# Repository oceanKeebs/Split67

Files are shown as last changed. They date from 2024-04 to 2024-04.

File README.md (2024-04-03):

# Split67

Split67 is a splitted common 67% ISO DE keyboard layout with processor daughterboards extended by a side case housing a TPS43 touch pad and a 64x128 Oled display. Left and right keyboard Pcb is connected with TRRS using serial communication, right keyboard part and sidecase are connected with TRRS using i2c communication. To support a close contact of the parts, magnets are used.

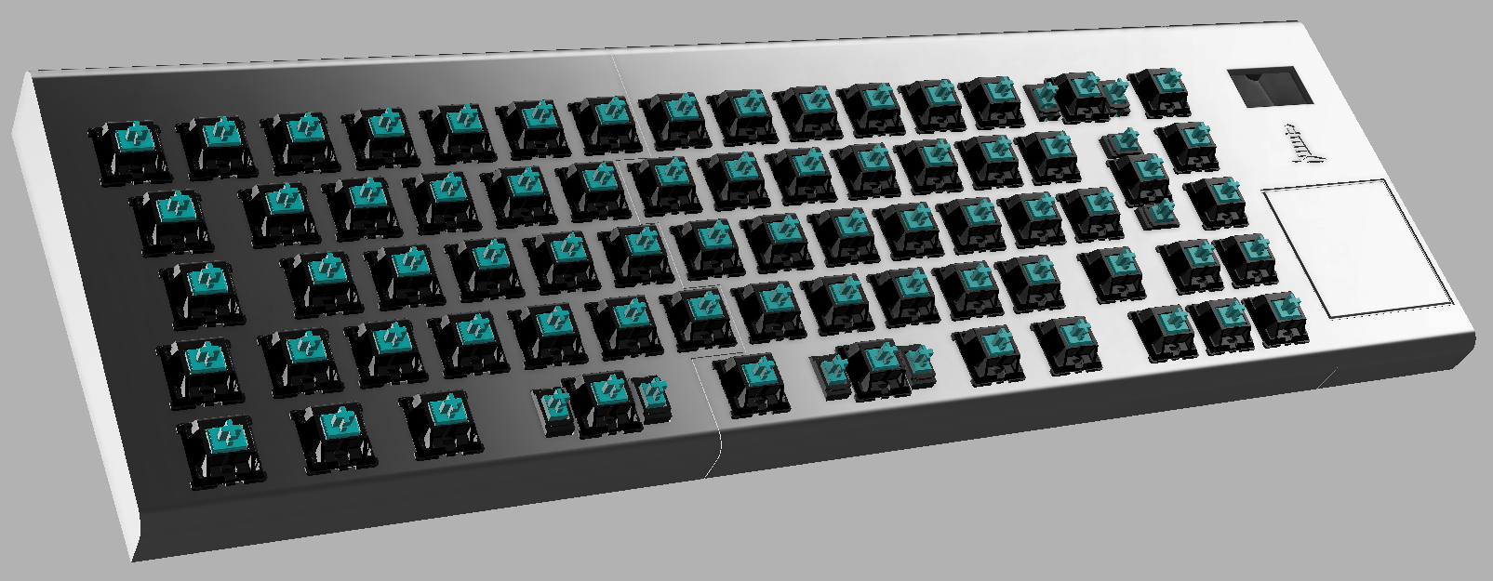
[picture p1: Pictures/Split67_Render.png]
Split67_Render


## QMK Firmware source files

<https://github.com/oceanKeebs/qmk_firmware/tree/master/keyboards/oceankeebs/split67>

## QMK Firmware hex files

**without via support:**
[Split67_defaultHex](HexFiles/oceankeebs_split67_default.hex)

**with via support:**
[Split67_viaHex](HexFiles/oceankeebs_split67_via.hex)

## PCBs

### Processor Board

The processor board includes the ProMicro and connectors for i2c, serial communication and keyboard Pcb control.

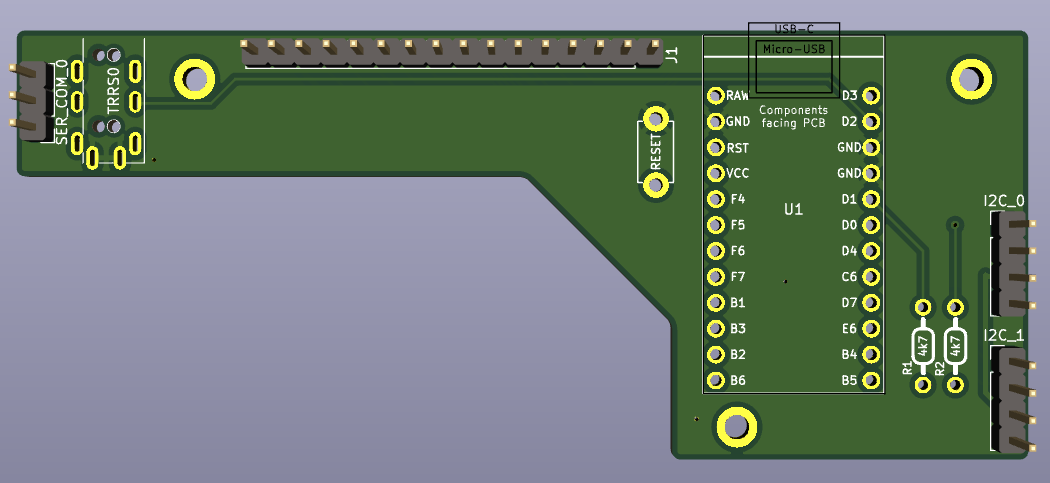
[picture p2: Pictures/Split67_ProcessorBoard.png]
Split67_ProcessorBoard


### Left Pcb

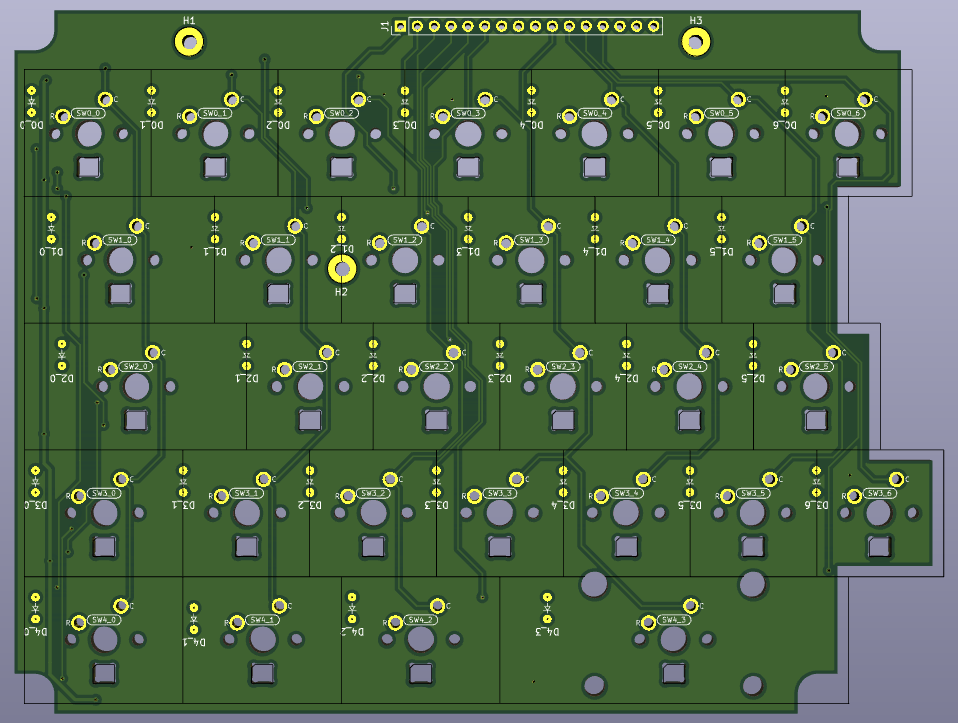
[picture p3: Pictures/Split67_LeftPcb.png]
Split67_LeftPcb


### Right Pcb

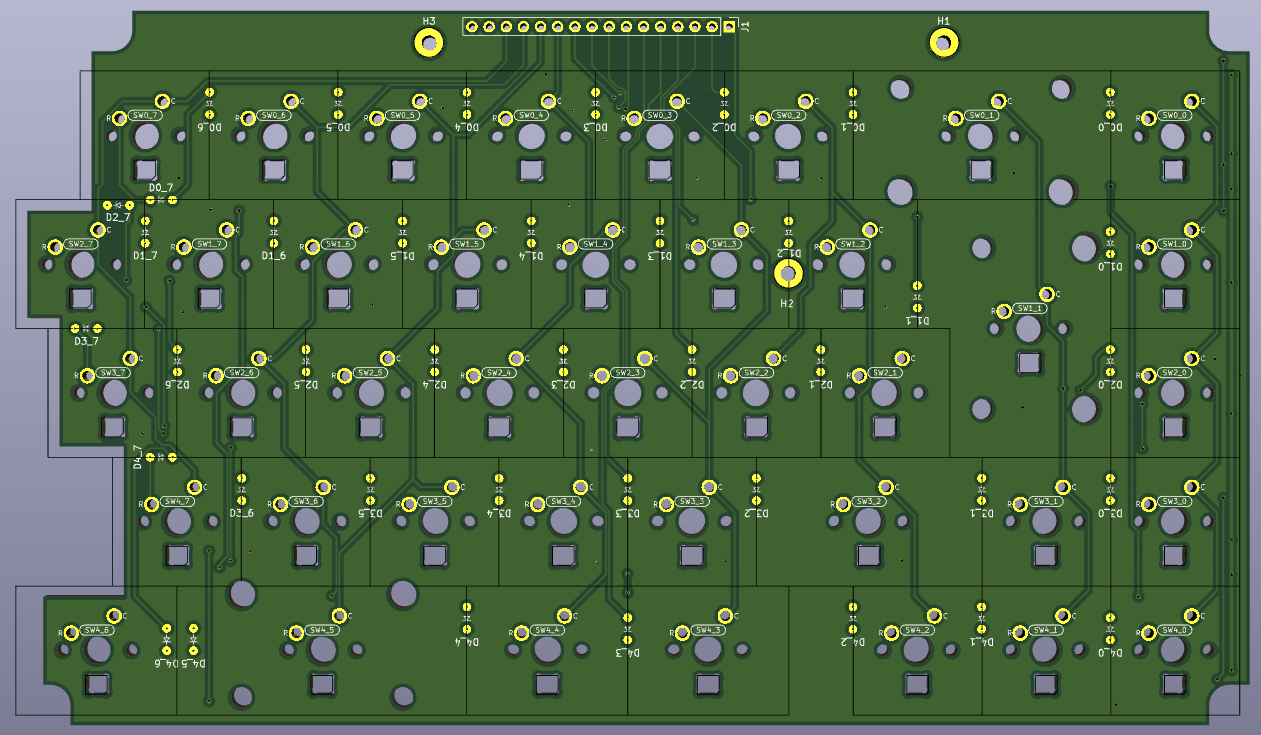
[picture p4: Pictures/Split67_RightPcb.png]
Split67_RightPcb


## Case

### Left keyboard part

[LeftCaseTop_stl](StlFiles/Case_L_B.stl)

[LeftCaseBottom_stl](StlFiles/Bottom_L.stl)

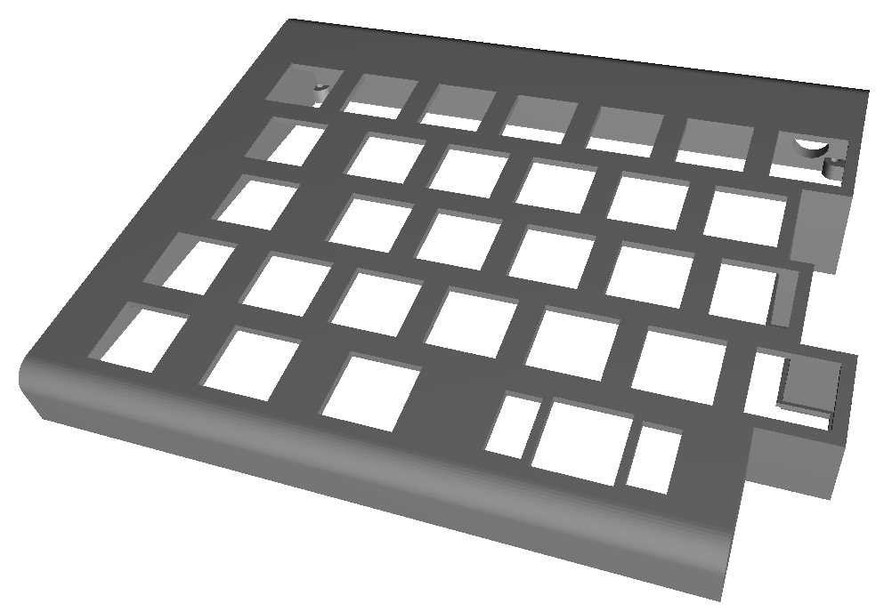
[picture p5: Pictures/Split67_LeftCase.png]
Split67_LeftCase


### Right keyboard part

[RightCaseTop_stl](StlFiles/Case_R_B.stl)

[RightCaseBottom_stl](StlFiles/Bottom_R.stl)

[UsbCoverBase_stl](StlFiles/USB-Cover_Base.stl)

[UsbCoverTop_stl](StlFiles/USB-Cover_Top.stl)

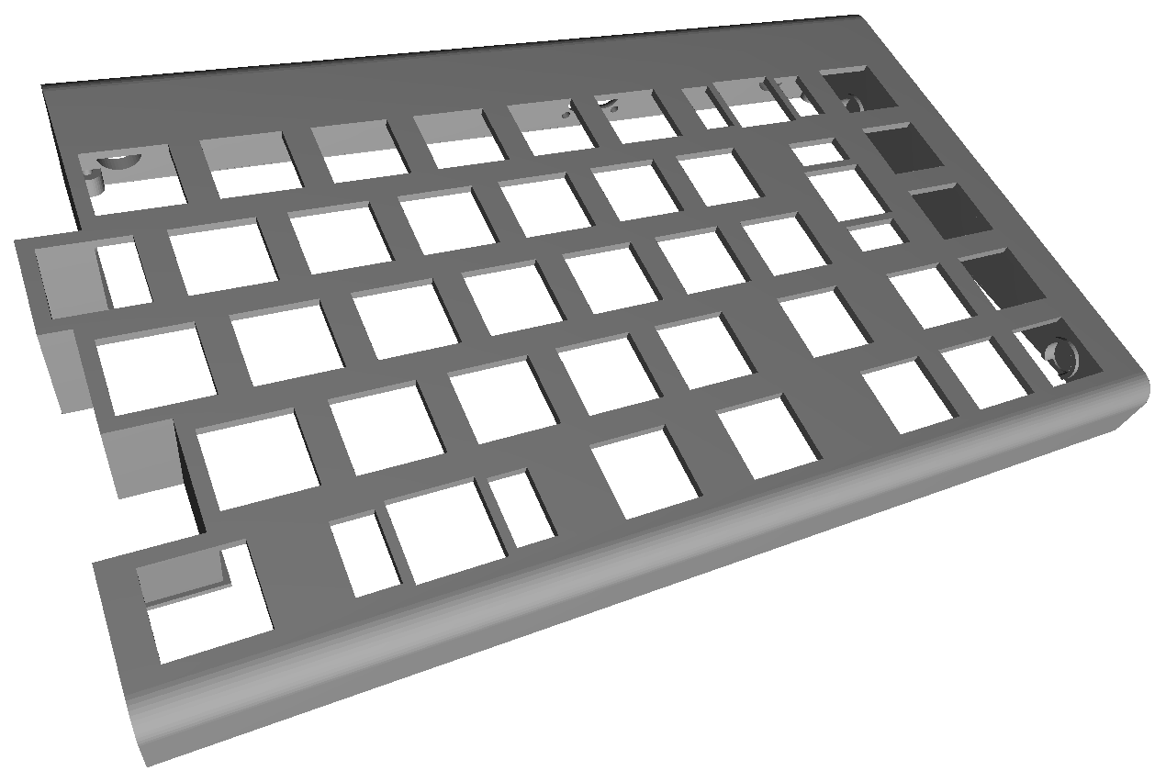
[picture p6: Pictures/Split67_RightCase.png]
Split67_RightCase


### SideCase

[SideCaseTop_stl](StlFiles/SideCase_B.stl)

[SideCaseBottom_stl](StlFiles/Bottom_Sidecase.stl)

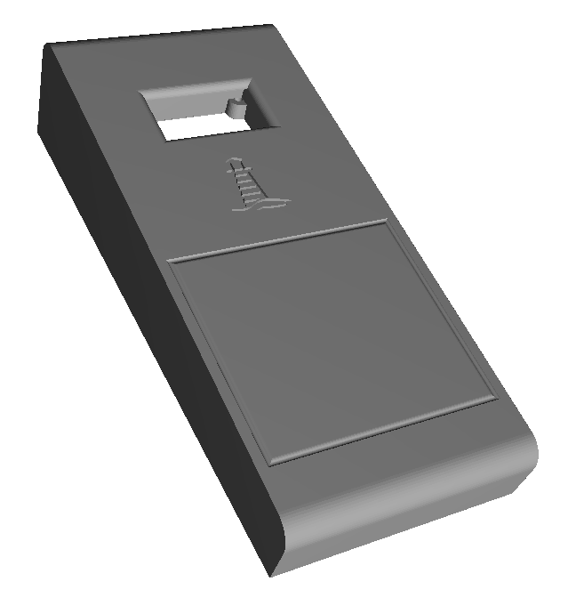
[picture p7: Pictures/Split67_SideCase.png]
Split67_SideCase


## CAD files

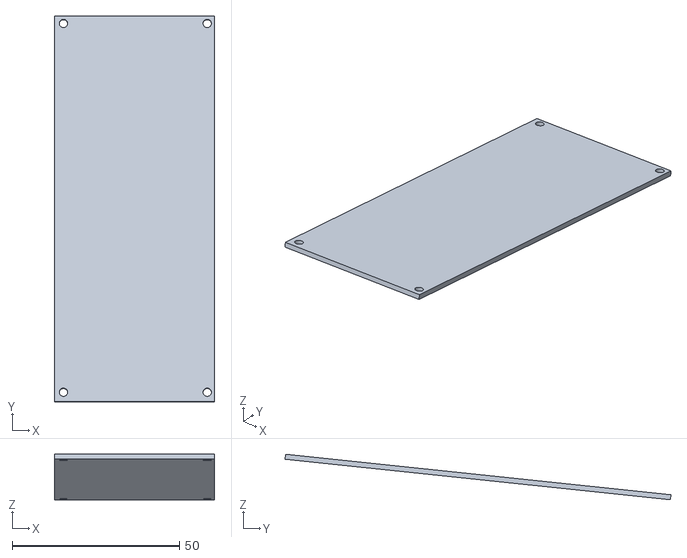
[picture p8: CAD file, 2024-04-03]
StlFiles/Bottom_Sidecase.stl
48.0 x 115.4 x 13.6

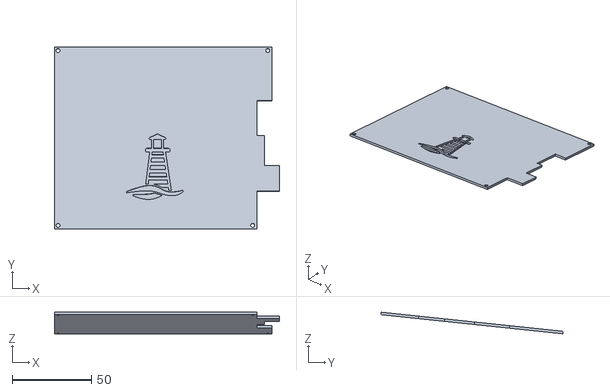
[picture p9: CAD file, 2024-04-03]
StlFiles/Bottom_L.stl
141.9 x 114.9 x 13.6

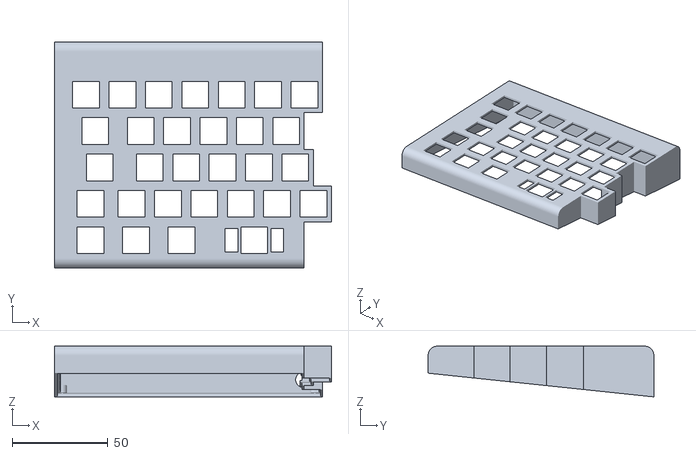
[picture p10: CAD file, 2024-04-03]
StlFiles/Case_L_B.stl
145.0 x 118.2 x 26.6

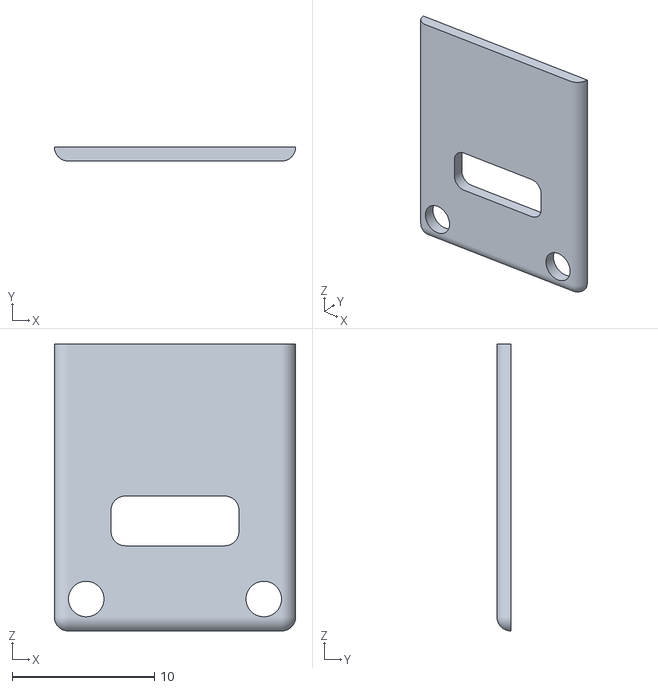
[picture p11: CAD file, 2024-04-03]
StlFiles/USB-Cover_Top.stl
17.0 x 1.00 x 20.2

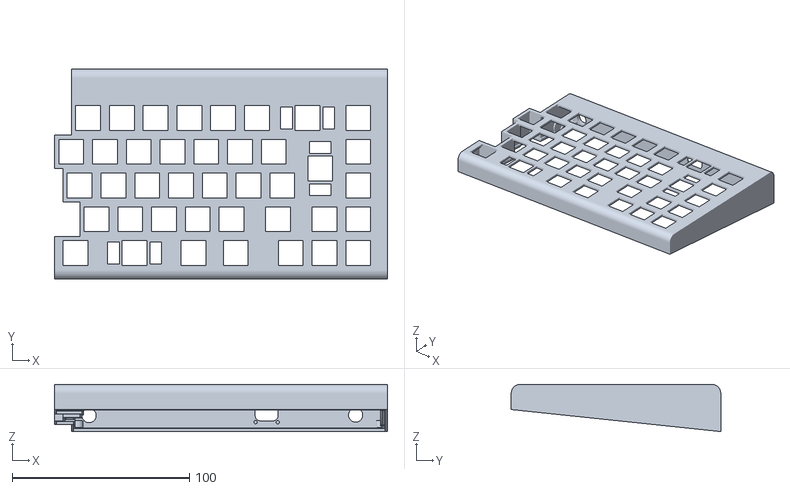
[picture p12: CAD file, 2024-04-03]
StlFiles/Case_R_B.stl
187.9 x 118.2 x 26.6

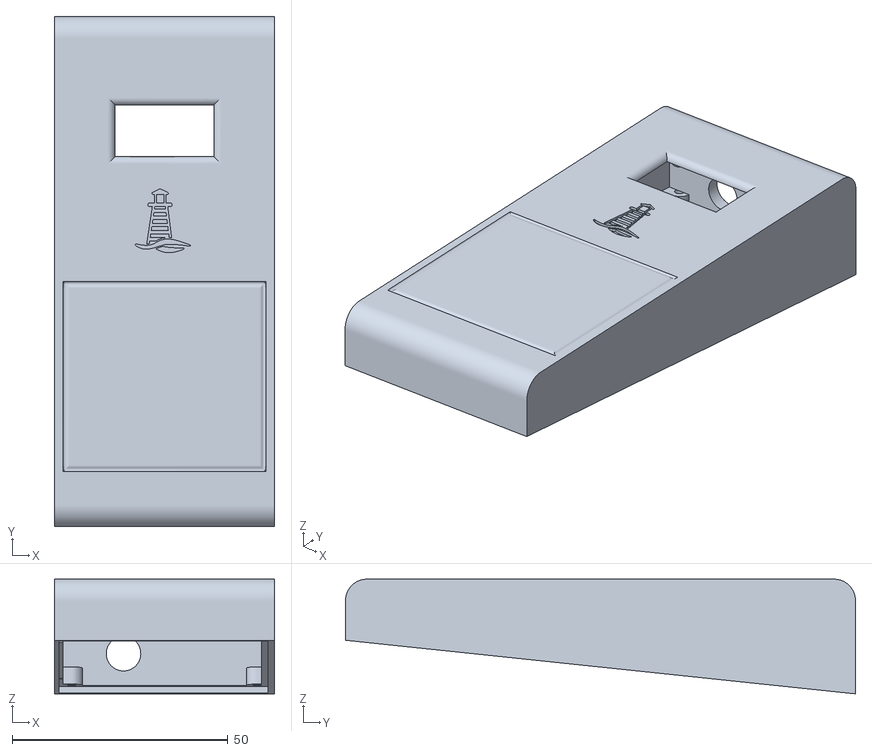
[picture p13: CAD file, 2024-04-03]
StlFiles/SideCase_B.stl
51.0 x 118.2 x 26.6

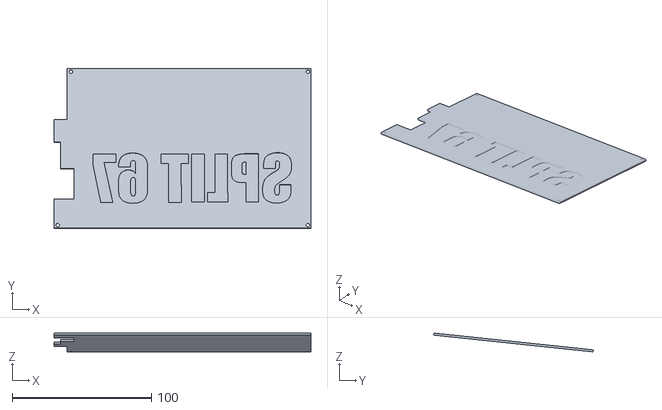
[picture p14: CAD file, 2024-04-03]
StlFiles/Bottom_R.stl
184.8 x 114.8 x 13.5

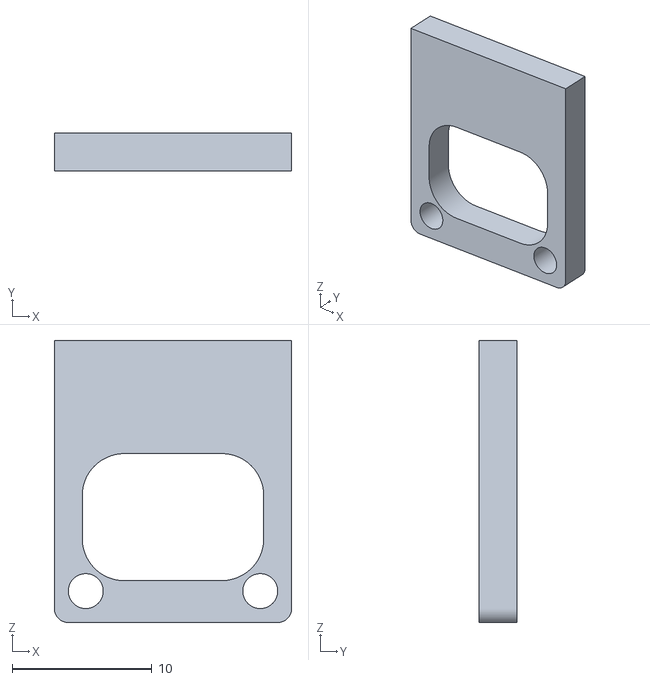
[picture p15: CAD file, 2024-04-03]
StlFiles/USB-Cover_Base.stl
17.0 x 2.72 x 20.2

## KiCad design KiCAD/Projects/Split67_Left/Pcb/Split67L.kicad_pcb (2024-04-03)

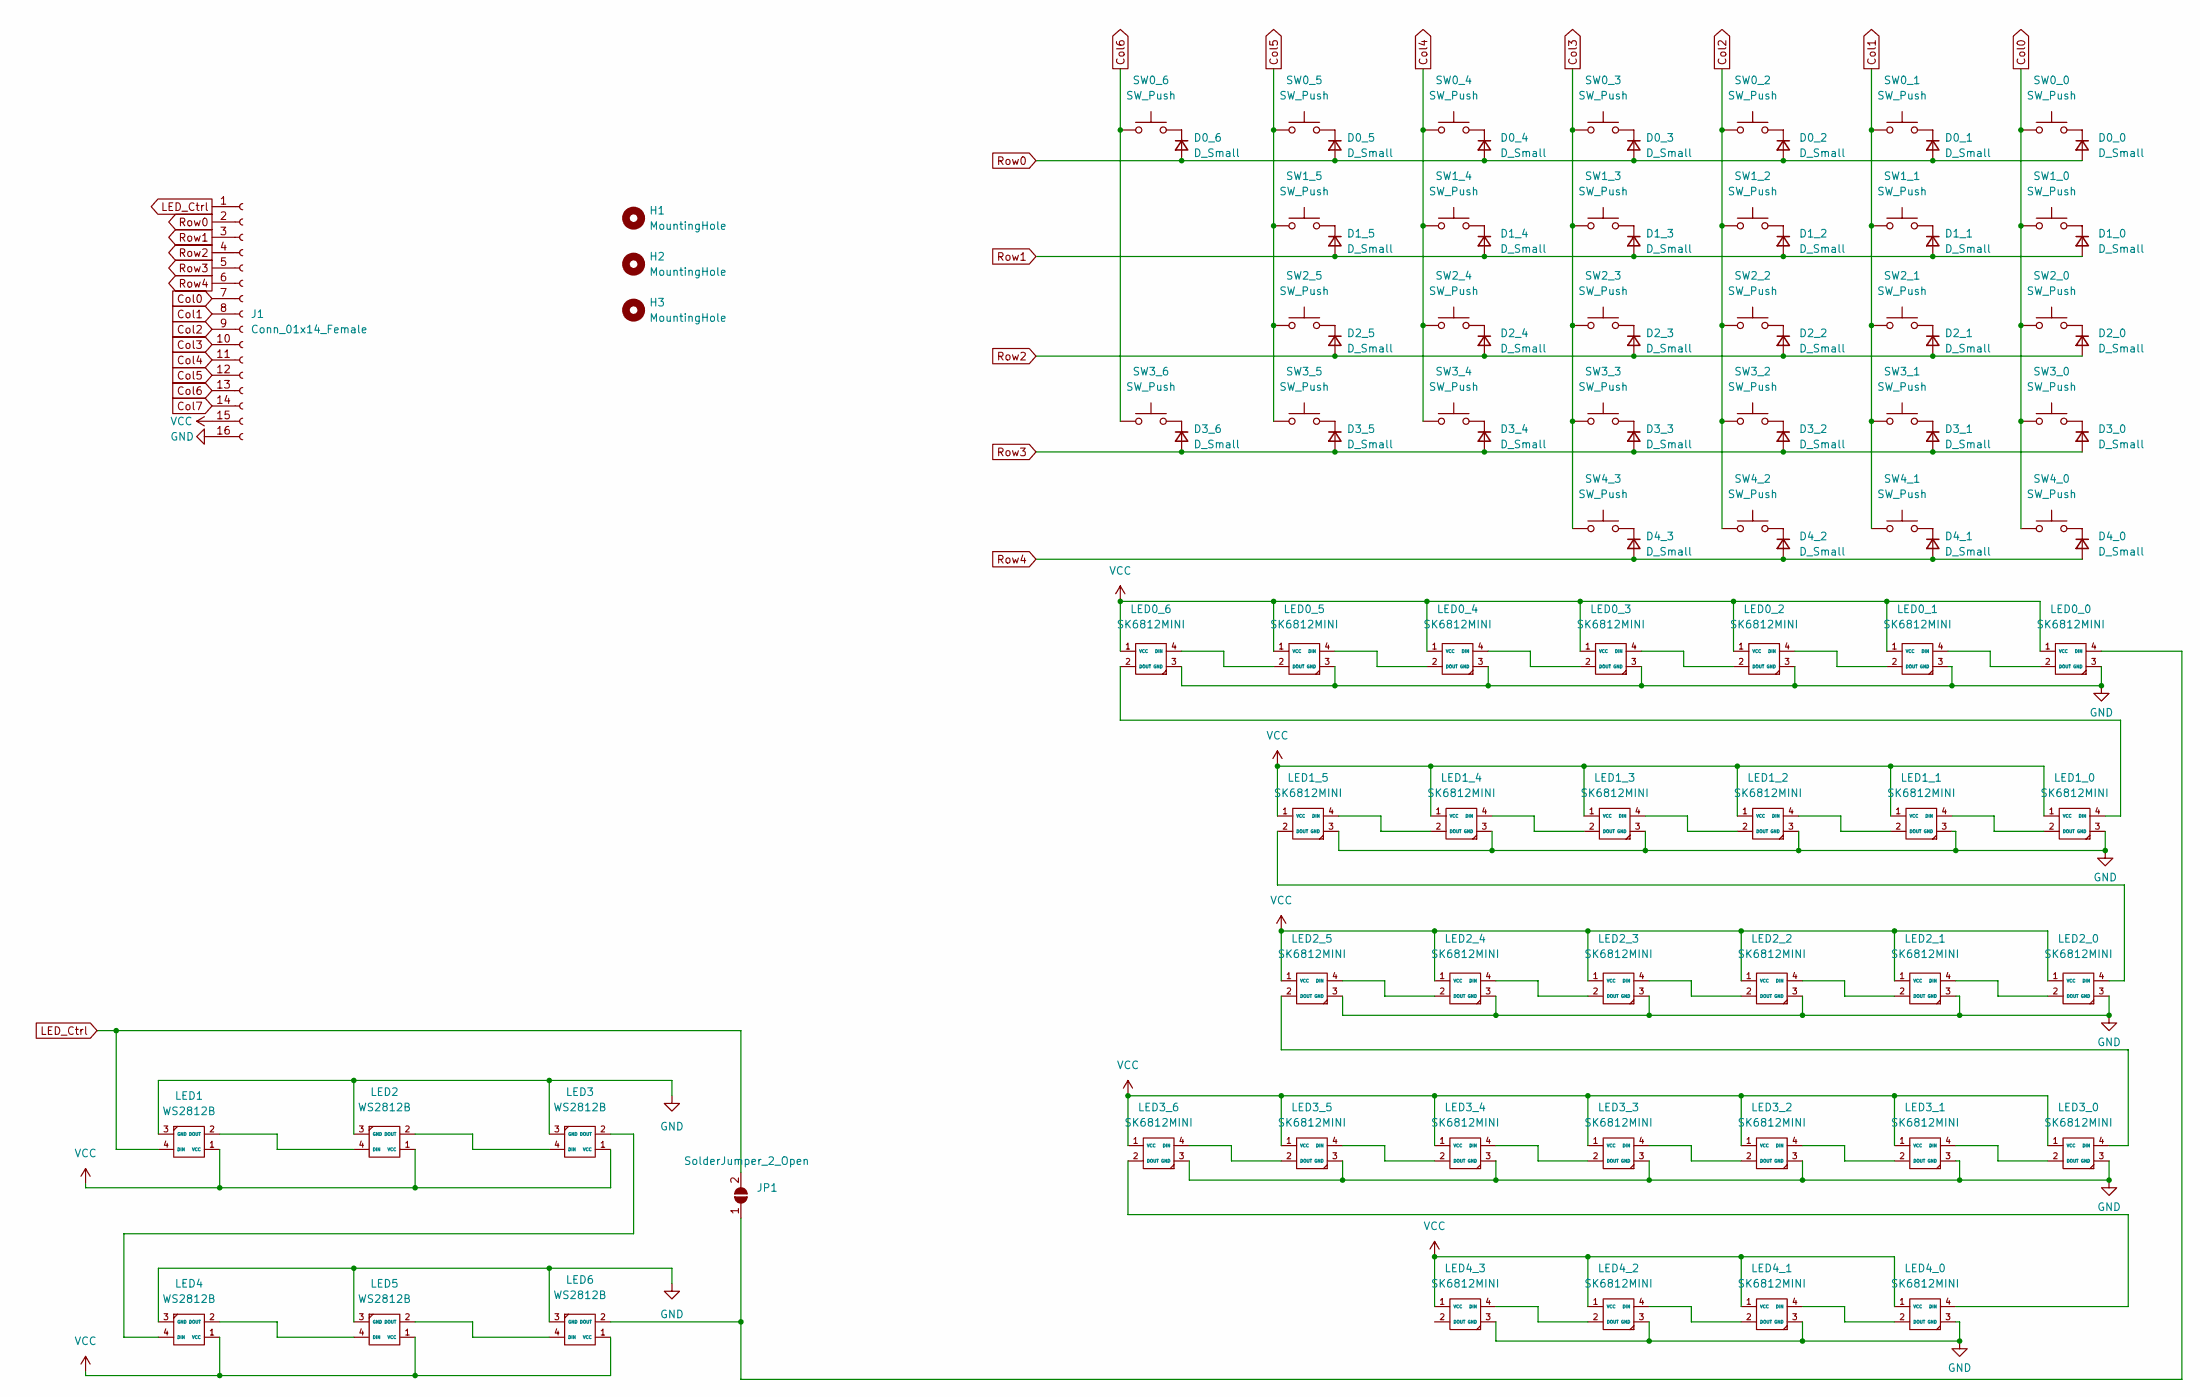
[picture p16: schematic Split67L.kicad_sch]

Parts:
D0_0, D0_1, D0_2, D0_3, D0_4, D0_5, D0_6, D1_0, D1_1, D1_2, D1_3, D1_4, D1_5, D2_0, D2_1, D2_2, D2_3, D2_4, D2_5, D3_0, D3_1, D3_2, D3_3, D3_4, D3_5, D3_6, D4_0, D4_1, D4_2, D4_3: D_Small; Diode_SMD_Round_Pads
H1, H2, H3: MountingHole; MountingHole_2.2mm_M2
J1: Conn_01x14_Female; PinHeader_1x16_P2.54mm_Vertical
JP1: SolderJumper_2_Open; SolderJumper-2_P1.3mm_Open_RoundedPad1.0x1.5mm
LED0_0, LED0_1, LED0_2, LED0_3, LED0_4, LED0_5, LED0_6, LED1_0, LED1_1, LED1_2, LED1_3, LED1_4, LED1_5, LED2_0, LED2_1, LED2_2, LED2_3, LED2_4, LED2_5, LED3_0, LED3_1, LED3_2, LED3_3, LED3_4, LED3_5, LED3_6, LED4_0, LED4_1, LED4_2, LED4_3: SK6812MINI; SK6812MiniE_MX_Addon_singlesided
LED1, LED2, LED3, LED4, LED5, LED6: WS2812B
SW0_0, SW0_1, SW0_2, SW0_3, SW0_4, SW0_5, SW0_6, SW1_1, SW1_2, SW1_3, SW1_4, SW1_5, SW2_1, SW2_2, SW2_3, SW2_4, SW2_5, SW3_1, SW3_2, SW3_3, SW3_4, SW3_5, SW3_6: SW_Push; MX_lss_100U
SW1_0: SW_Push; MX_lss_150U
SW2_0: SW_Push; MX_lss_175U
SW3_0, SW4_0, SW4_1, SW4_2: SW_Push; MX_lss_125U
SW4_3: SW_Push; MX_lss_275U_StWN

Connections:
Col0: J1.7, SW0_0.1, SW1_0.1, SW2_0.1, SW3_0.1, SW4_0.1
Col1: J1.8, SW0_1.1, SW1_1.1, SW2_1.1, SW3_1.1, SW4_1.1
Col2: J1.9, SW0_2.1, SW1_2.1, SW2_2.1, SW3_2.1, SW4_2.1
Col3: J1.10, SW0_3.1, SW1_3.1, SW2_3.1, SW3_3.1, SW4_3.1
Col4: J1.11, SW0_4.1, SW1_4.1, SW2_4.1, SW3_4.1
Col5: J1.12, SW0_5.1, SW1_5.1, SW2_5.1, SW3_5.1
Col6: J1.13, SW0_6.1, SW3_6.1
Col7: J1.14
GND: J1.16, LED0_0.3 (GND), LED0_1.3 (GND), LED0_2.3 (GND), LED0_3.3 (GND), LED0_4.3 (GND), LED0_5.3 (GND), LED0_6.3 (GND), LED1.3 (GND), LED1_0.3 (GND), LED1_1.3 (GND), LED1_2.3 (GND), LED1_3.3 (GND), LED1_4.3 (GND), LED1_5.3 (GND), LED2.3 (GND), LED2_0.3 (GND), LED2_1.3 (GND), LED2_2.3 (GND), LED2_3.3 (GND), LED2_4.3 (GND), LED2_5.3 (GND), LED3.3 (GND), LED3_0.3 (GND), LED3_1.3 (GND), LED3_2.3 (GND), LED3_3.3 (GND), LED3_4.3 (GND), LED3_5.3 (GND), LED3_6.3 (GND), LED4.3 (GND), LED4_0.3 (GND), LED4_1.3 (GND), LED4_2.3 (GND), LED4_3.3 (GND), LED5.3 (GND), LED6.3 (GND)
LED_Ctrl: J1.1, JP1.2 (B), LED1.4 (DIN)
unnamed: D0_0.1 (K), SW0_0.2
unnamed: D0_1.1 (K), SW0_1.2
unnamed: D0_2.1 (K), SW0_2.2
unnamed: D0_3.1 (K), SW0_3.2
unnamed: D0_4.1 (K), SW0_4.2
unnamed: D0_5.1 (K), SW0_5.2
unnamed: D1_0.1 (K), SW1_0.2
unnamed: D1_1.1 (K), SW1_1.2
unnamed: D1_2.1 (K), SW1_2.2
unnamed: D1_3.1 (K), SW1_3.2
unnamed: D1_4.1 (K), SW1_4.2
unnamed: D1_5.1 (K), SW1_5.2
unnamed: D2_0.1 (K), SW2_0.2
unnamed: D2_1.1 (K), SW2_1.2
unnamed: D2_2.1 (K), SW2_2.2
unnamed: D2_3.1 (K), SW2_3.2
unnamed: D2_4.1 (K), SW2_4.2
unnamed: D2_5.1 (K), SW2_5.2
unnamed: D3_0.1 (K), SW3_0.2
unnamed: D3_1.1 (K), SW3_1.2
unnamed: D3_2.1 (K), SW3_2.2
unnamed: D3_3.1 (K), SW3_3.2
unnamed: D3_4.1 (K), SW3_4.2
unnamed: D3_5.1 (K), SW3_5.2
unnamed: D4_0.1 (K), SW4_0.2
unnamed: D4_1.1 (K), SW4_1.2
unnamed: D4_2.1 (K), SW4_2.2
unnamed: JP1.1 (A), LED0_0.4 (DIN), LED6.2 (DOUT)
unnamed: LED0_0.2 (DOUT), LED0_1.4 (DIN)
unnamed: LED0_1.2 (DOUT), LED0_2.4 (DIN)
unnamed: LED0_2.2 (DOUT), LED0_3.4 (DIN)
unnamed: LED0_3.2 (DOUT), LED0_4.4 (DIN)
unnamed: LED0_4.2 (DOUT), LED0_5.4 (DIN)
unnamed: LED0_5.2 (DOUT), LED0_6.4 (DIN)
unnamed: LED1.2 (DOUT), LED2.4 (DIN)
unnamed: LED1_0.2 (DOUT), LED1_1.4 (DIN)
unnamed: LED0_6.2 (DOUT), LED1_0.4 (DIN)
unnamed: LED1_1.2 (DOUT), LED1_2.4 (DIN)
unnamed: LED1_2.2 (DOUT), LED1_3.4 (DIN)
unnamed: LED1_3.2 (DOUT), LED1_4.4 (DIN)
unnamed: LED1_4.2 (DOUT), LED1_5.4 (DIN)
unnamed: LED2.2 (DOUT), LED3.4 (DIN)
unnamed: LED2_0.2 (DOUT), LED2_1.4 (DIN)
unnamed: LED1_5.2 (DOUT), LED2_0.4 (DIN)
unnamed: LED2_1.2 (DOUT), LED2_2.4 (DIN)
unnamed: LED2_2.2 (DOUT), LED2_3.4 (DIN)
unnamed: LED2_3.2 (DOUT), LED2_4.4 (DIN)
unnamed: LED2_4.2 (DOUT), LED2_5.4 (DIN)
unnamed: LED3.2 (DOUT), LED4.4 (DIN)
unnamed: LED3_0.2 (DOUT), LED3_1.4 (DIN)
unnamed: LED2_5.2 (DOUT), LED3_0.4 (DIN)
unnamed: LED3_1.2 (DOUT), LED3_2.4 (DIN)
unnamed: LED3_2.2 (DOUT), LED3_3.4 (DIN)
unnamed: LED3_3.2 (DOUT), LED3_4.4 (DIN)
unnamed: LED3_4.2 (DOUT), LED3_5.4 (DIN)
unnamed: LED3_5.2 (DOUT), LED3_6.4 (DIN)
unnamed: LED4.2 (DOUT), LED5.4 (DIN)
unnamed: LED4_0.2 (DOUT), LED4_1.4 (DIN)
unnamed: LED3_6.2 (DOUT), LED4_0.4 (DIN)
unnamed: LED4_1.2 (DOUT), LED4_2.4 (DIN)
unnamed: LED4_2.2 (DOUT), LED4_3.4 (DIN)
unnamed: LED5.2 (DOUT), LED6.4 (DIN)
unnamed: D0_6.1 (K), SW0_6.2
unnamed: D3_6.1 (K), SW3_6.2
unnamed: D4_3.1 (K), SW4_3.2
Row0: D0_0.2 (A), D0_1.2 (A), D0_2.2 (A), D0_3.2 (A), D0_4.2 (A), D0_5.2 (A), D0_6.2 (A), J1.2
Row1: D1_0.2 (A), D1_1.2 (A), D1_2.2 (A), D1_3.2 (A), D1_4.2 (A), D1_5.2 (A), J1.3
Row2: D2_0.2 (A), D2_1.2 (A), D2_2.2 (A), D2_3.2 (A), D2_4.2 (A), D2_5.2 (A), J1.4
Row3: D3_0.2 (A), D3_1.2 (A), D3_2.2 (A), D3_3.2 (A), D3_4.2 (A), D3_5.2 (A), D3_6.2 (A), J1.5
Row4: D4_0.2 (A), D4_1.2 (A), D4_2.2 (A), D4_3.2 (A), J1.6
VCC: J1.15, LED0_0.1 (VCC), LED0_1.1 (VCC), LED0_2.1 (VCC), LED0_3.1 (VCC), LED0_4.1 (VCC), LED0_5.1 (VCC), LED0_6.1 (VCC), LED1.1 (VCC), LED1_0.1 (VCC), LED1_1.1 (VCC), LED1_2.1 (VCC), LED1_3.1 (VCC), LED1_4.1 (VCC), LED1_5.1 (VCC), LED2.1 (VCC), LED2_0.1 (VCC), LED2_1.1 (VCC), LED2_2.1 (VCC), LED2_3.1 (VCC), LED2_4.1 (VCC), LED2_5.1 (VCC), LED3.1 (VCC), LED3_0.1 (VCC), LED3_1.1 (VCC), LED3_2.1 (VCC), LED3_3.1 (VCC), LED3_4.1 (VCC), LED3_5.1 (VCC), LED3_6.1 (VCC), LED4.1 (VCC), LED4_0.1 (VCC), LED4_1.1 (VCC), LED4_2.1 (VCC), LED4_3.1 (VCC), LED5.1 (VCC), LED6.1 (VCC)

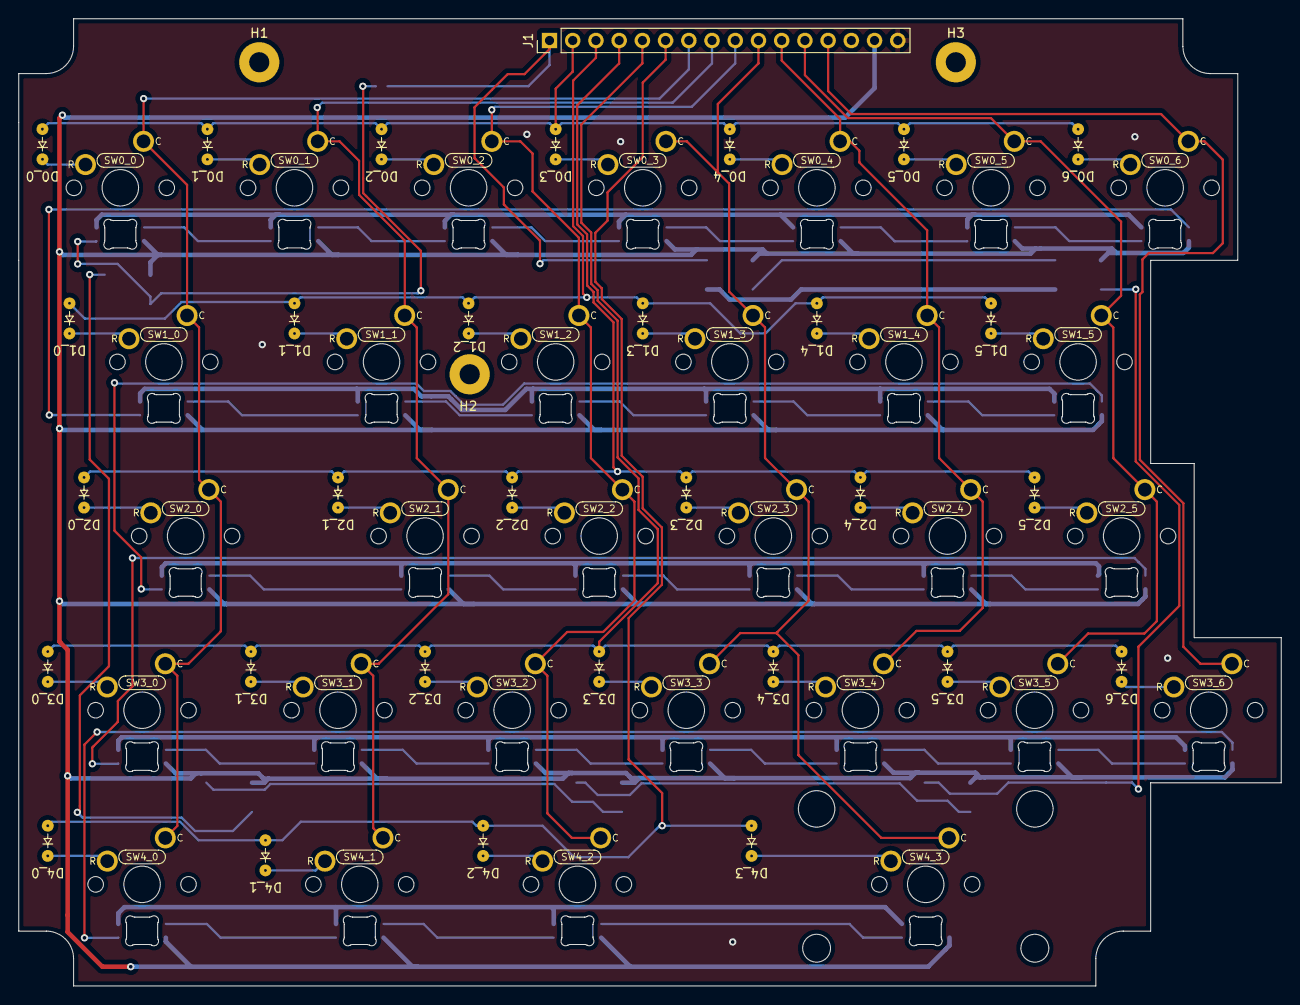
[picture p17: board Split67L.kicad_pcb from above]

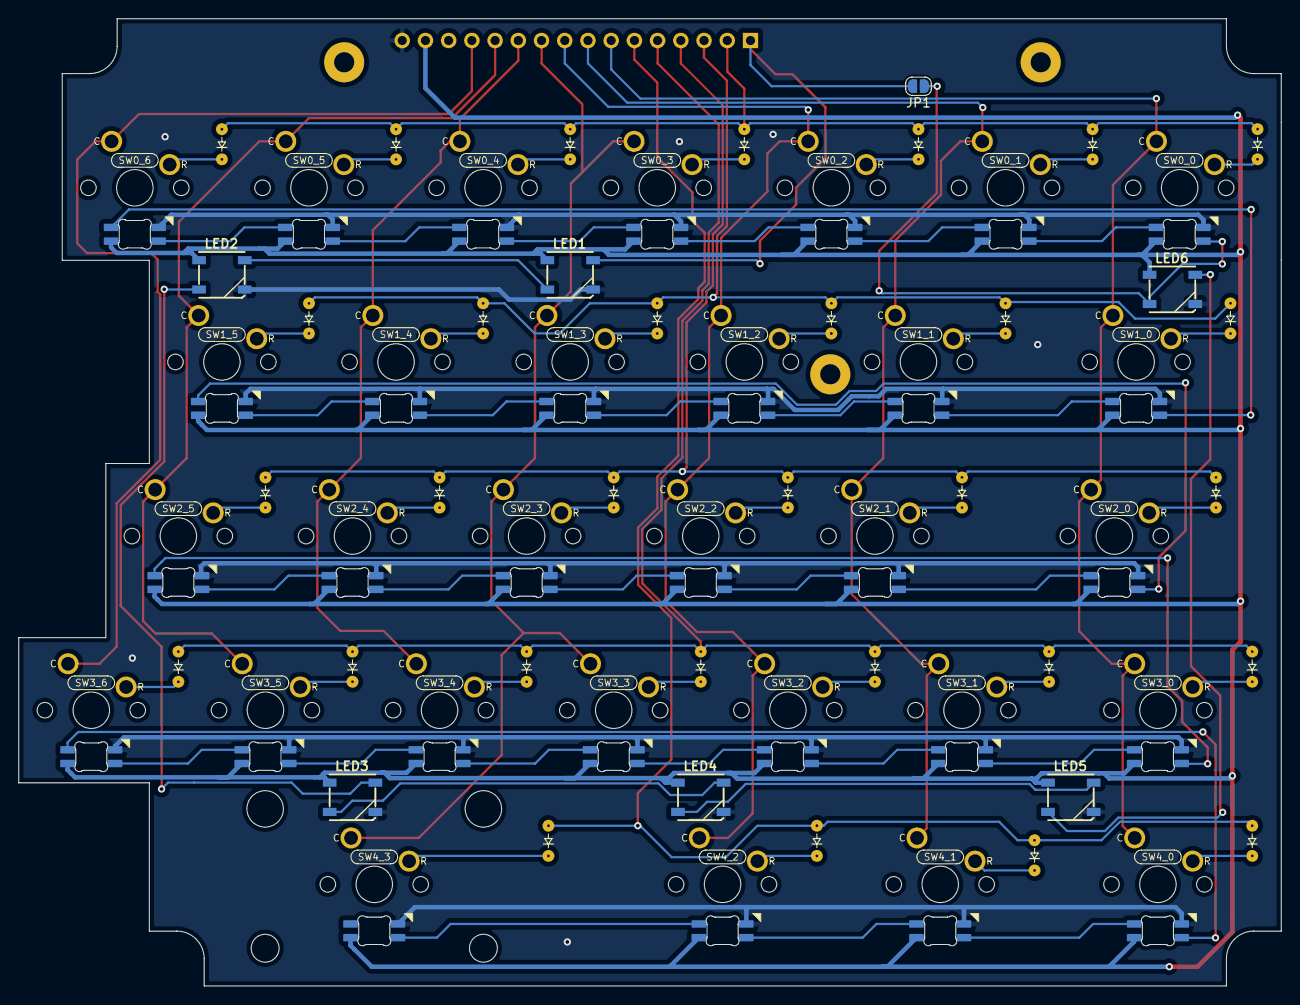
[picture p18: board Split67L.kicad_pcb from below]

Board: 2 copper layers, 138.1 x 105.8 mm, 101 parts (7 on the bottom side), 80 nets.

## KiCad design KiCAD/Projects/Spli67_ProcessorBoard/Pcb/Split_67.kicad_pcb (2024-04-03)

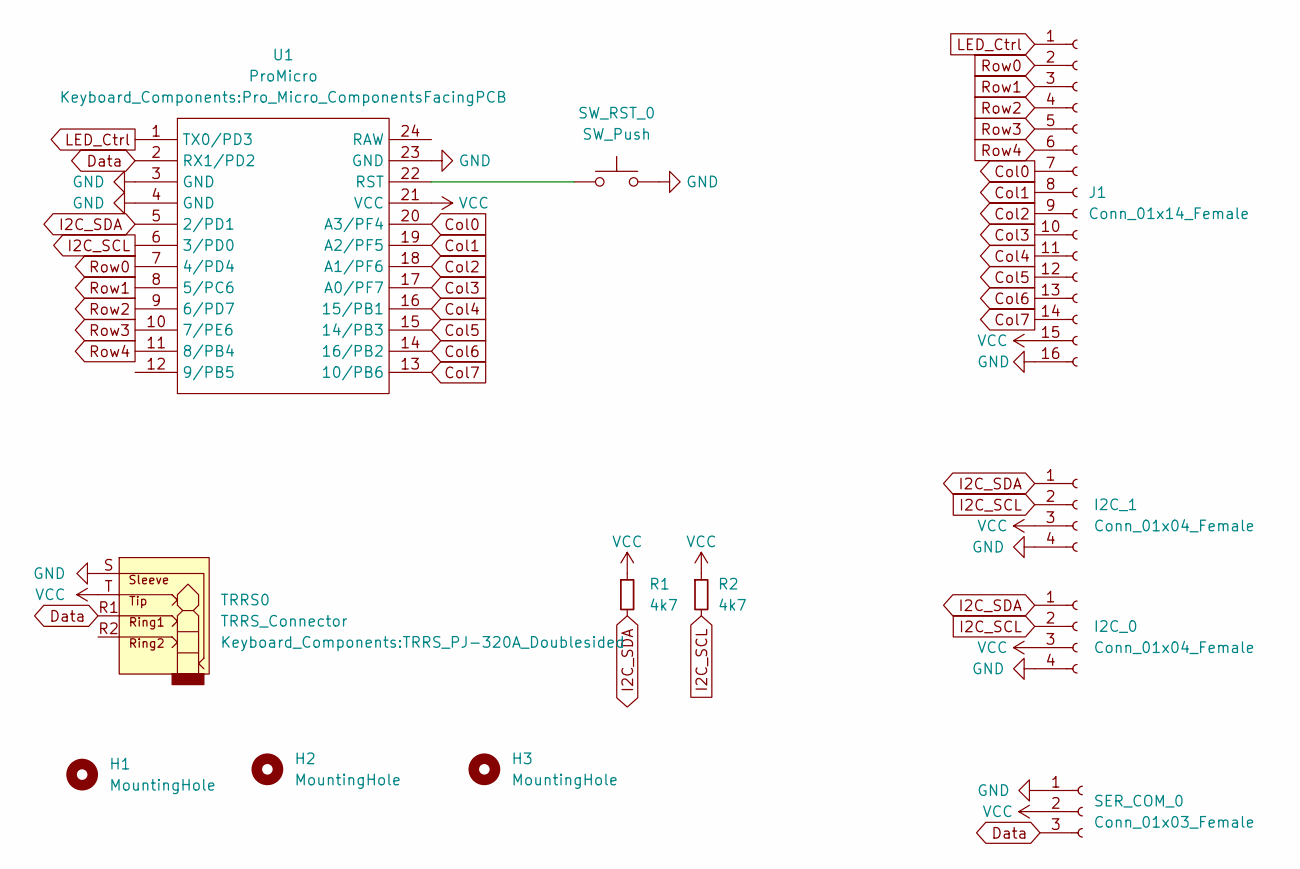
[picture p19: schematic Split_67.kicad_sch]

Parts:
H1, H2, H3: MountingHole; M2_Mountinghole
I2C_0, I2C_1: Conn_01x04_Female; PinHeader_1x04_P2.54mm_Vertical
J1: Conn_01x14_Female; PinHeader_1x16_P2.54mm_Vertical
R1, R2: 4k7; Resistor
SER_COM_0: Conn_01x03_Female; PinHeader_1x03_P2.54mm_Vertical
SW_RST_0: SW_Push; Reset_Switch
TRRS0: TRRS_Connector; TRRS_PJ-320A_Doublesided
U1: ProMicro; Pro_Micro_ComponentsFacingPCB

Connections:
Col0: J1.7, U1.20 (A3/PF4)
Col1: J1.8, U1.19 (A2/PF5)
Col2: J1.9, U1.18 (A1/PF6)
Col3: J1.10, U1.17 (A0/PF7)
Col4: J1.11, U1.16 (15/PB1)
Col5: J1.12, U1.15 (14/PB3)
Col6: J1.13, U1.14 (16/PB2)
Col7: J1.14, U1.13 (10/PB6)
Data: SER_COM_0.3, TRRS0.R1, U1.2 (RX1/PD2)
GND: I2C_0.4, I2C_1.4, J1.16, SER_COM_0.1, SW_RST_0.2, TRRS0.S, U1.3 (GND), U1.4 (GND), U1.23 (GND)
I2C_SCL: I2C_0.2, I2C_1.2, R2.2, U1.6 (3/PD0)
I2C_SDA: I2C_0.1, I2C_1.1, R1.2, U1.5 (2/PD1)
LED_Ctrl: J1.1, U1.1 (TX0/PD3)
unnamed: SW_RST_0.1, U1.22 (RST)
Row0: J1.2, U1.7 (4/PD4)
Row1: J1.3, U1.8 (5/PC6)
Row2: J1.4, U1.9 (6/PD7)
Row3: J1.5, U1.10 (7/PE6)
Row4: J1.6, U1.11 (8/PB4)
VCC: I2C_0.3, I2C_1.3, J1.15, R1.1, R2.1, SER_COM_0.2, TRRS0.T, U1.21 (VCC)

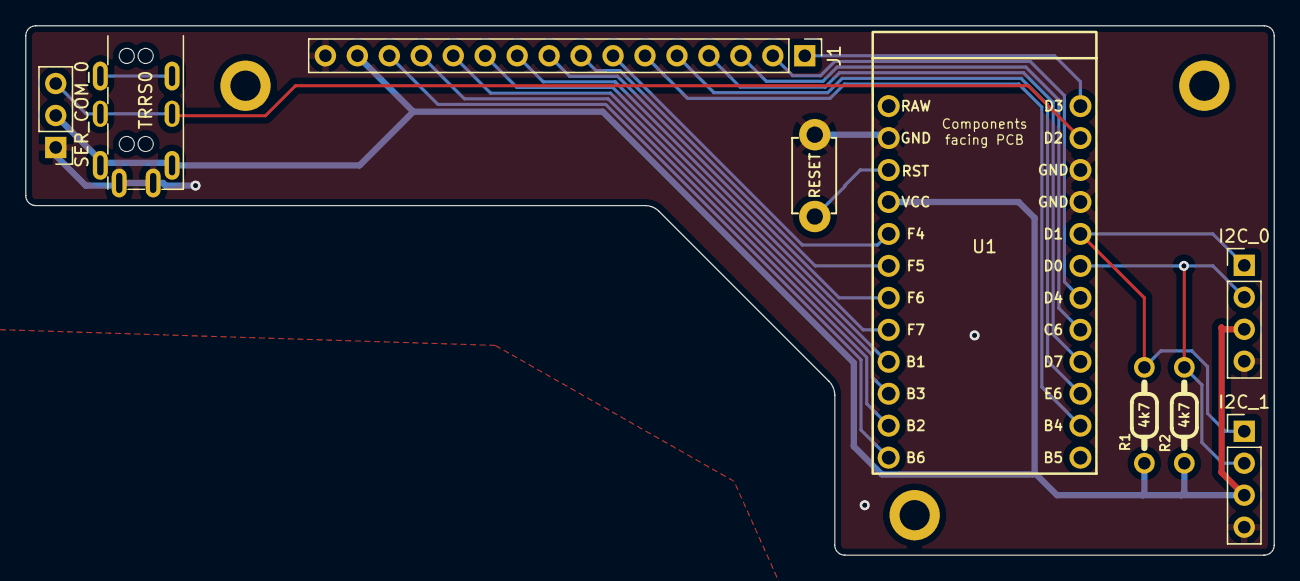
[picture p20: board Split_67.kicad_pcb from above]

Board: 2 copper layers, 99.2 x 42.1 mm, 12 parts (0 on the bottom side), 20 nets.
